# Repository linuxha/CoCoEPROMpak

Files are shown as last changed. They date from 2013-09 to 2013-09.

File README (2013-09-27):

CoCoEPROMpak 1.0
Copyright 2013 by Mark J. Blair
Distributed under GPLv3

CoCoEPROMpak is a PCB design for an EPROM-based ROM cartridge for the
Tandy/TRS-80 Color Computer. It can accept on 2732, 2764, 27128, 27256
or 27512 EPROM. Board thickness must be 0.062". Gold plating is
preferable to avoid contact oxidation. Board is designed to the
OSHpark design rules for a 2-layer PCB.

When using 27256 or larger EPROMs, the EPROM is divided into 2-4 16k
banks which can be selected with jumper settings. Jumper settings are
also important for 27256 and smaller EPROMs in order to apply the
correct power and control signals to the EPROM.

4k:
    * Install 2732 at U1
    * JP2, JP3 not used
8k:
    * Install 2764 at U2
    * Set JP2 to 1
    * Set JP3 to 1
16k:
    * Install 27128 at U2
    * Set JP2 to 1
    * Set JP3 to 1
32k:
    * Install 27256 at U2
    * Select 16k bank with JP2
    * Set JP3 to 1
64k:
    * Install 27512 at U2
    * Select 16k banks with JP2 and JP3

CoCoEPROMpak is a free hardware design: you can redistribute it and/or
modify it under the terms of the GNU General Public License as
published by the Free Software Foundation, either version 3 of the
License, or (at your option) any later version.

CoCoEPROMpak is distributed in the hope that it will be useful, but
WITHOUT ANY WARRANTY; without even the implied warranty of
MERCHANTABILITY or FITNESS FOR A PARTICULAR PURPOSE. See the GNU
General Public License for more details.

You should have received a copy of the GNU General Public License
along with CoCoEPROMpak. If not, see <http://www.gnu.org/licenses/>.

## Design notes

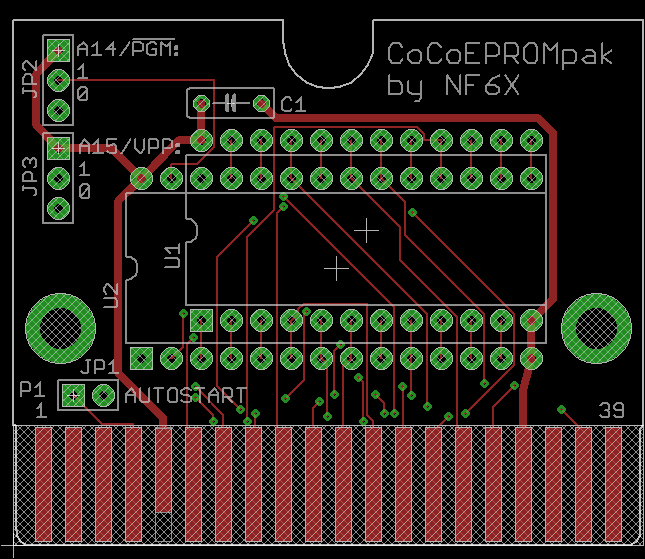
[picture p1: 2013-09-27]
Top.png

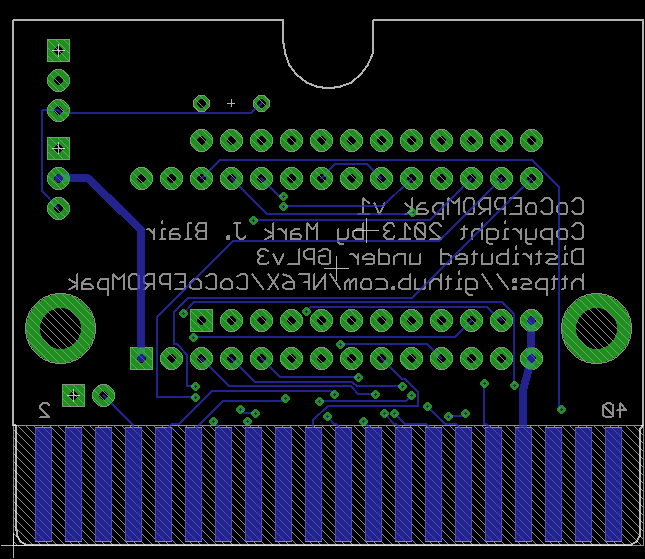
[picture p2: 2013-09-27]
Bottom.png

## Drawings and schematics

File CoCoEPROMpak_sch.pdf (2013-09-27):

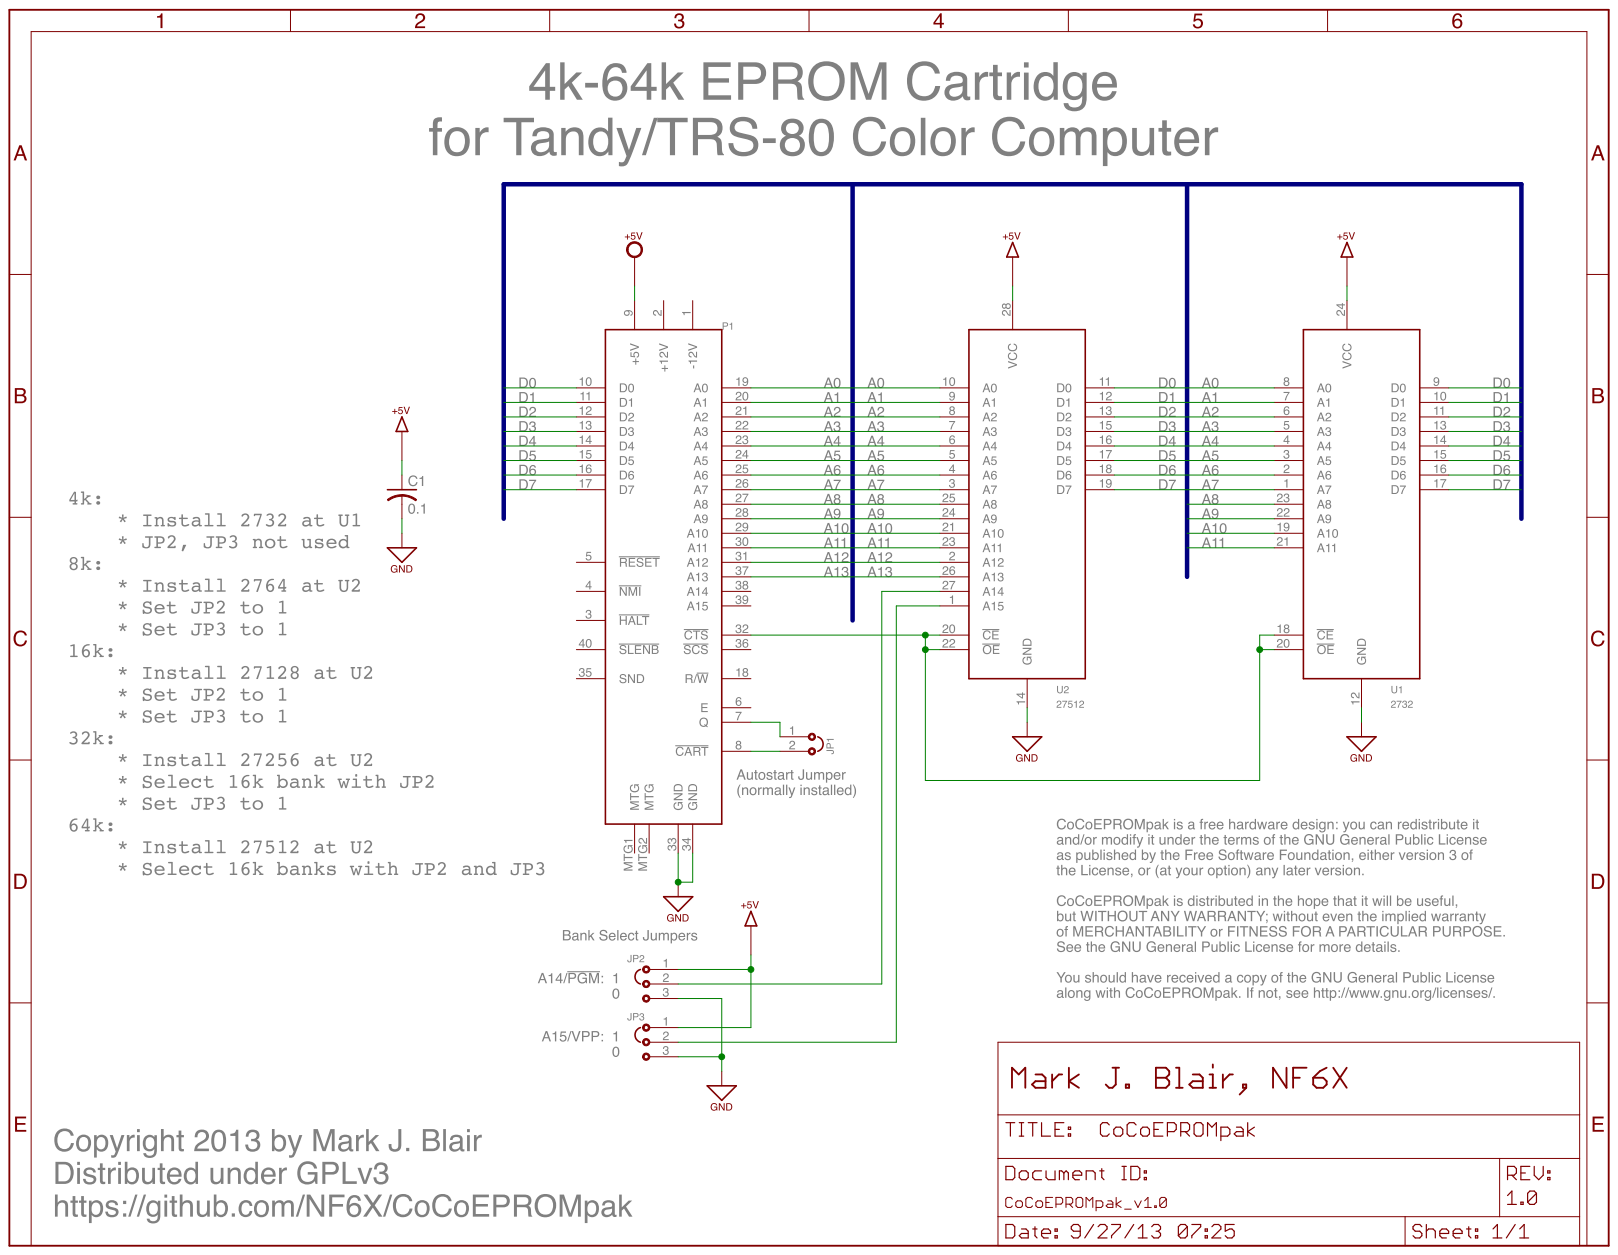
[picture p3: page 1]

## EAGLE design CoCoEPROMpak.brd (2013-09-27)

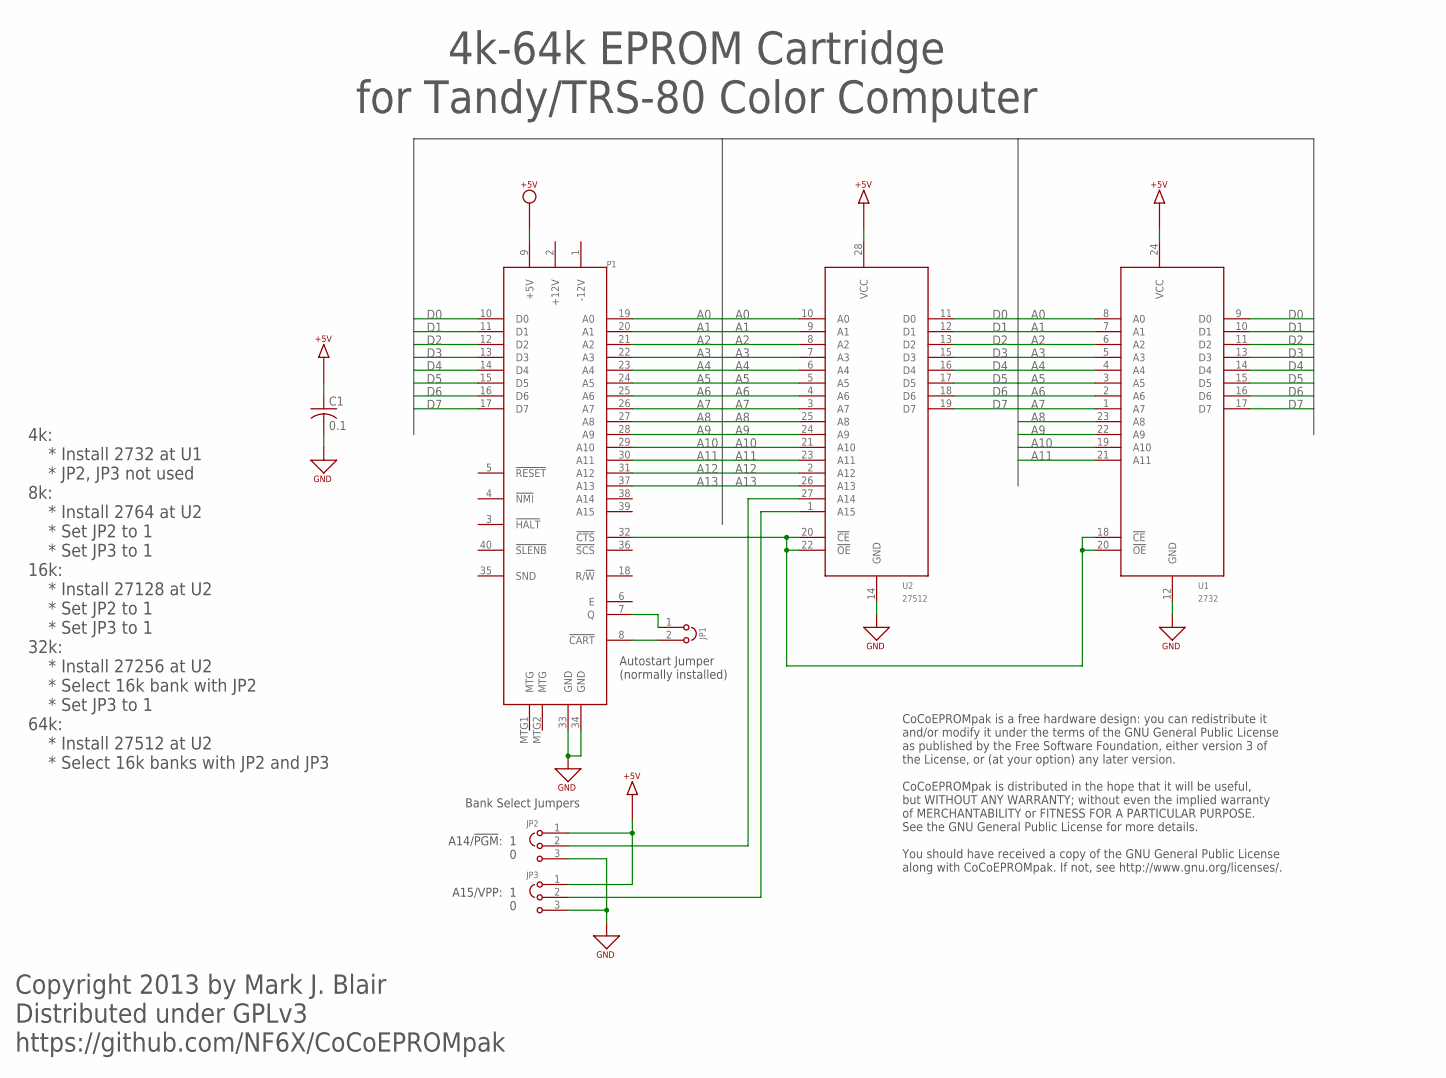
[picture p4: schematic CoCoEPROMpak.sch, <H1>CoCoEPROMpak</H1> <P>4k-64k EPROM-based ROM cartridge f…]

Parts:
C1: 0.1; C050-025X075
JP1: JP2; JP2-100MIL
JP2, JP3: JP3; JP3-100MIL
P1: COCO-CART; COCO-CART-2.1X1.75
U1: 2732; DIL24
U2: 27512; DIL28

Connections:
+5V: C1.1, JP2.1, JP3.1, P1.9 (+5V), U1.24 (VCC), U2.28 (VCC)
A0: P1.19 (A0), U1.8 (A0), U2.10 (A0)
A1: P1.20 (A1), U1.7 (A1), U2.9 (A1)
A2: P1.21 (A2), U1.6 (A2), U2.8 (A2)
A3: P1.22 (A3), U1.5 (A3), U2.7 (A3)
A4: P1.23 (A4), U1.4 (A4), U2.6 (A4)
A5: P1.24 (A5), U1.3 (A5), U2.5 (A5)
A6: P1.25 (A6), U1.2 (A6), U2.4 (A6)
A7: P1.26 (A7), U1.1 (A7), U2.3 (A7)
A8: P1.27 (A8), U1.23 (A8), U2.25 (A8)
A9: P1.28 (A9), U1.22 (A9), U2.24 (A9)
A10: P1.29 (A10), U1.19 (A10), U2.21 (A10)
A11: P1.30 (A11), U1.21 (A11), U2.23 (A11)
A12: P1.31 (A12), U2.2 (A12)
A13: P1.37 (A13), U2.26 (A13)
D0: P1.10 (D0), U1.9 (D0), U2.11 (D0)
D1: P1.11 (D1), U1.10 (D1), U2.12 (D1)
D2: P1.12 (D2), U1.11 (D2), U2.13 (D2)
D3: P1.13 (D3), U1.13 (D3), U2.15 (D3)
D4: P1.14 (D4), U1.14 (D4), U2.16 (D4)
D5: P1.15 (D5), U1.15 (D5), U2.17 (D5)
D6: P1.16 (D6), U1.16 (D6), U2.18 (D6)
D7: P1.17 (D7), U1.17 (D7), U2.19 (D7)
GND: C1.2, JP2.3, JP3.3, P1.33 (GND), P1.34 (GND), U1.12 (GND), U2.14 (GND)
unnamed: JP2.2, U2.27 (A14)
unnamed: P1.32 (!CTS), U1.18 (!CE), U1.20 (!OE), U2.20 (!CE), U2.22 (!OE)
unnamed: JP3.2, U2.1 (A15)
unnamed: JP1.2, P1.8 (!CART)
unnamed: JP1.1, P1.7 (Q)

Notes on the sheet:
Autostart Jumper (normally installed)
4k-64k EPROM Cartridge for Tandy/TRS-80 Color Computer
Copyright 2013 by Mark J. Blair Distributed under GPLv3 https://github.com/NF6X/CoCoEPROMpak
Bank Select Jumpers
4k: * Install 2732 at U1 * JP2, JP3 not used 8k: * Install 2764 at U2 * Set JP2 to 1 * Set JP3 to 1 16k: * Install 27128 at U2 * Set JP2 to 1 * Set JP3 to 1 32k: * Install 27256 at U2 * Select 16k bank with JP2 * Set JP3 to 1 64k: * Install 27512 at U2 * Select 16k banks with JP2 and JP3
CoCoEPROMpak is a free hardware design: you can redistribute it and/or modify it under the terms of the GNU General Public License as published by the Free Software Foundation, either version 3 of the License, or (at your option) any later version. CoCoEPROMpak is distributed in the hope that it wi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
A14/!PGM!: 1 0
A15/VPP: 1 0

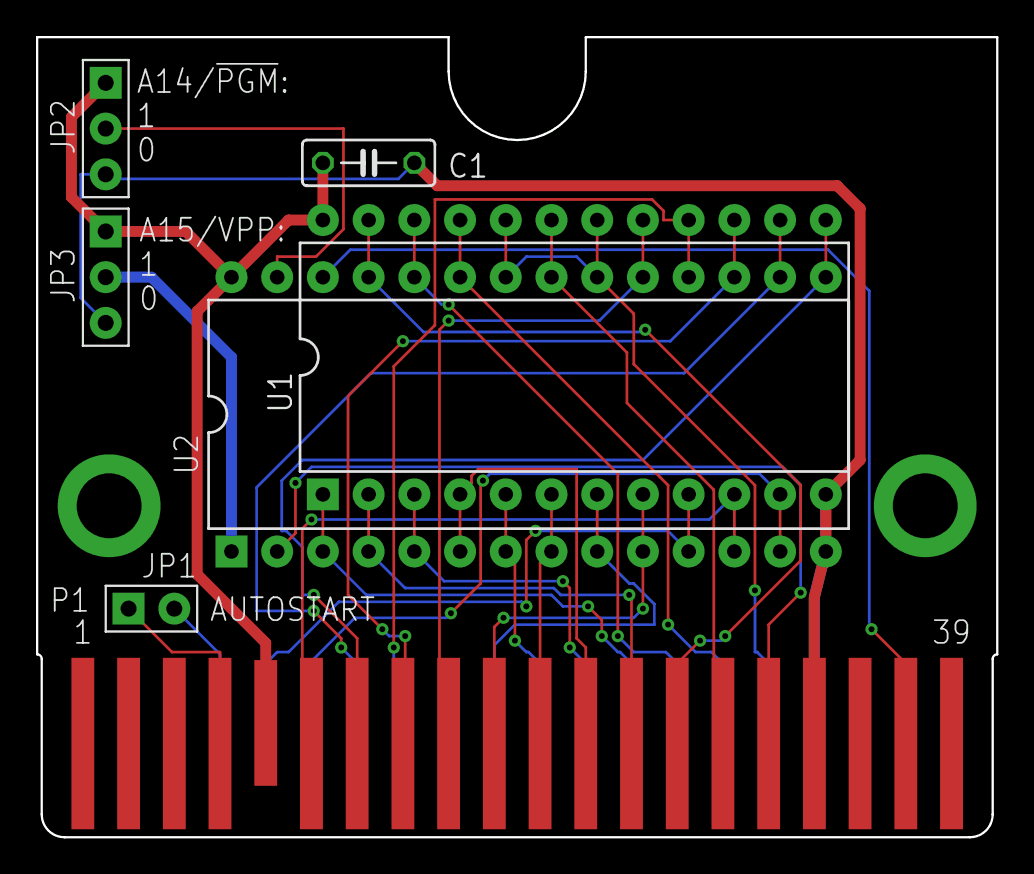
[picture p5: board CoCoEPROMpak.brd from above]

Board: 2 copper layers, 53.3 x 44.5 mm, 7 parts (0 on the bottom side), 29 nets.

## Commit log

2013-09-26 Initial commit.
    [CoCoEPROMpak.brd, CoCoEPROMpak.sch]
2013-09-26 Typo correction.
    [CoCoEPROMpak.brd]
2013-09-26 Added Gerber outputs. Corrected fonts for proper output.
    [CoCoEPROMpak.brd, CoCoEPROMpak.sch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]
2013-09-26 Added support for 27256 and 27512 EPROMs with bank-switching by jumper settings.
    [CoCoEPROMpak.brd, CoCoEPROMpak.sch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]
2013-09-26 Corrected reference designators in configuration documentation on schematic.
    [CoCoEPROMpak.sch]
2013-09-27 Documentation improvements.
    [CoCoEPROMpak.brd, CoCoEPROMpak.sch]

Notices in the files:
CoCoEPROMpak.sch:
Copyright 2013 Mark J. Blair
